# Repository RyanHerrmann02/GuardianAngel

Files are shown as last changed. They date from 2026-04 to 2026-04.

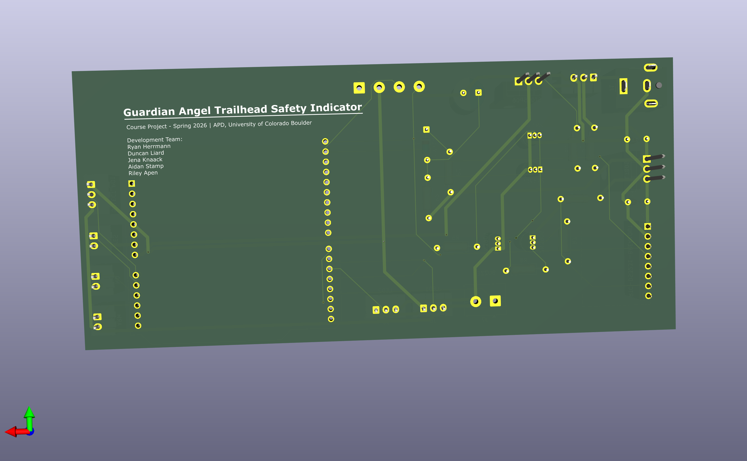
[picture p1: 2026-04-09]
ProtoBoard/Board_Rendering_Bottom.png

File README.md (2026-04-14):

# Guardian Angel
**Course Project — Spring 2026 | APD, University of Colorado Boulder**

## Overview
Guardian Angel is an Arduino-based trailhead safety indicator designed to assist 
Search and Rescue (SAR) personnel and other outdoor enthusiasts to communicate the status of
users when in the backcountry. This project was developed as part of the
Advanced Product Design (APD) course Spring 2026 at the University of Colorado Boulder.

## Hardware Architecture

### Power Management
A core engineering challenge of this project was designing a reliable power sequencing
system that allows the Arduino to control its own power state while also being woken
remotely by an RTC alarm all from a single LiPo battery source with no dedicated
power management IC.

#### Passive Power Latch (RC Hold Circuit)
To allow the Arduino to hold itself powered on after the user presses the power switch,
a passive PMOS-based power latch was designed and verified through SPICE simulation.
On power switch press, an RC circuit (47kΩ / 100µF, τ ≈ 4.7s) pulls the PMOS gate low
long enough for the Arduino to boot and assert its own hold pin, latching the board on
indefinitely. To enable fast and reliable resets, an asymmetric discharge path was
implemented using a 1kΩ resistor in series with a flyback diode in parallel with the
charge resistor, reducing the discharge time constant to ~100ms. This ensures the latch
clears quickly and cleanly between power cycles without requiring any active components.

#### RTC Wake Circuit (Discrete Transistor Level Shifter)
The DS3231 RTC module operates on a 5V rail that remains powered after the Arduino board 
is fully shut off, minimizing system current draw during the wait period. This allows the 
RTC to continue tracking time and fire a wake alarm via its open-drain SQW pin when the 
countdown expires. The PMOS transistor, which is responsible for gating battery voltage 
into the Arduino, requires its gate to be pulled low at battery voltage (~7.4V) to power 
the board back on a different domain from the 5V RTC supply. A two-stage discrete 
transistor circuit was designed to bridge these domains without connecting them directly. 
When the SQW pin fires and pulls low, current flows
through a PNP transistor biased from the 5V rail, whose collector output drives the base
of an NPN transistor referenced to ground. The NPN collector then pulls the PMOS gate
low at battery voltage, turning the board back on. This keeps the 5V RTC supply domain
fully isolated from the battery voltage domain while reliably translating the alarm signal
into a board power-on event.

---

## Future Development
Long-range wireless communication via LoRa radio integration is currently under 
consideration for future iterations of the project. This would enable communication 
between trail indicators and users within certain ranges. Implementation is subject 
to project timeline and scope constraints.

Developing a single board to handle functions with DS3231 breakout and a microcontroller
like the ATtiny for logic and pin control. This will also net in better power consumption
and longer battery life.

## Repository Contents
The following files are included in this repository:

| File | Description |
|---|---|
| `BasicBoardTesting.ino` | "Sandbox" for testing board pulldown transistor testing for utilizing PMOS for board power. |
| `GACarCommand.ino` | Primary device firmware handling LCD display, RTC alarm scheduling, and emergency lighting. |
| `HelloWorld.ino` | Basic LCD I2C display verification test. |
| `ProtoBoard` | Schematics and Gerber files for prototyped board using Arduino shield for component integration. Included is zip of Gerber drill files. |
| `RFReceiveCommand.ino` | Test file for receiving LoRa radio commands, displaying results on an LCD and controlling corresponding LEDs. |
| `RFSendCommand.ino` | Test file for transmitting LoRa radio commands, using a potentiometer to select color-coded signal states. |
| `RTCPullDown.ino` | Final testing with RTC breakout to verify SQW pin pulls down to turn on PMOS. |
| `SleepBreakouTest.ino` | Initial test code for RTC breakout to track time. |
| `SleepCommandDemo.ino` | Initial test code for UI interfacing with buttons and potentiometer to set time. |
| `TurnOnDemo.ino` | Basic verification for turn on and check for Alarm state. |

## Development Team
- Ryan Herrmann
- Duncan Liard
- Jena Knaack
- Aidan Stamp
- Riley Apen

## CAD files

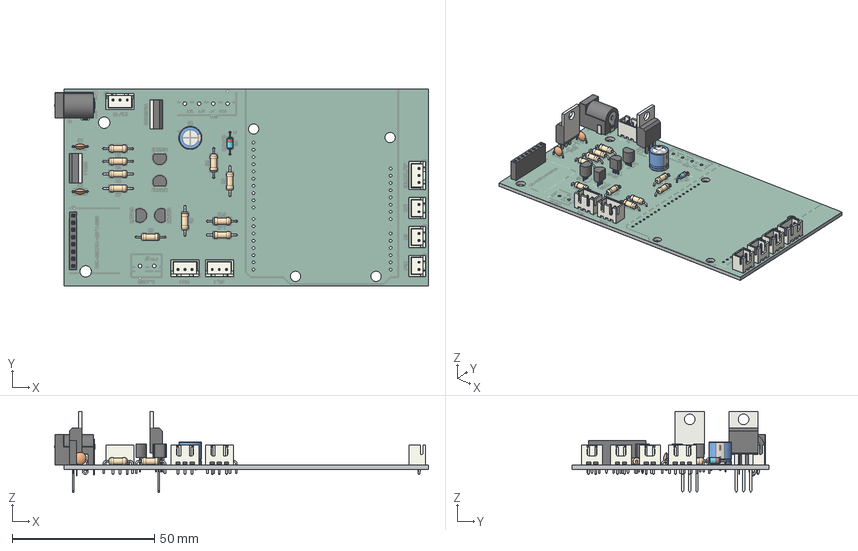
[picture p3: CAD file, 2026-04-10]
ProtoBoard/FullGACommand.step
131.6 x 69.2 x 28.5 mm
R_Axial_DIN0207_L6.3mm_D2.5mm_P10.16mm_Horizontal x 10
TO-220-3_Vertical x 2
BarrelJack_Horizontal
C_Disc_D4.3mm_W1.9mm_P5.00mm x 2
TO-92_Inline x 4
CP_Radial_D8.0mm_P3.80mm
PinSocket_1x08_P2.54mm_Vertical
JST_XH_B2B-XH-A_1x02_P2.50mm_Vertical x 3
JST_XH_B3B-XH-A_1x03_P2.50mm_Vertical x 4
D_DO-35_SOD27_P7.62mm_Horizontal
FullGACommand_silkscreen x 2
FullGACommand_soldermask x 2
FullGACommand_PCB

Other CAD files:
ProtoBoard/FullGACommand.stl

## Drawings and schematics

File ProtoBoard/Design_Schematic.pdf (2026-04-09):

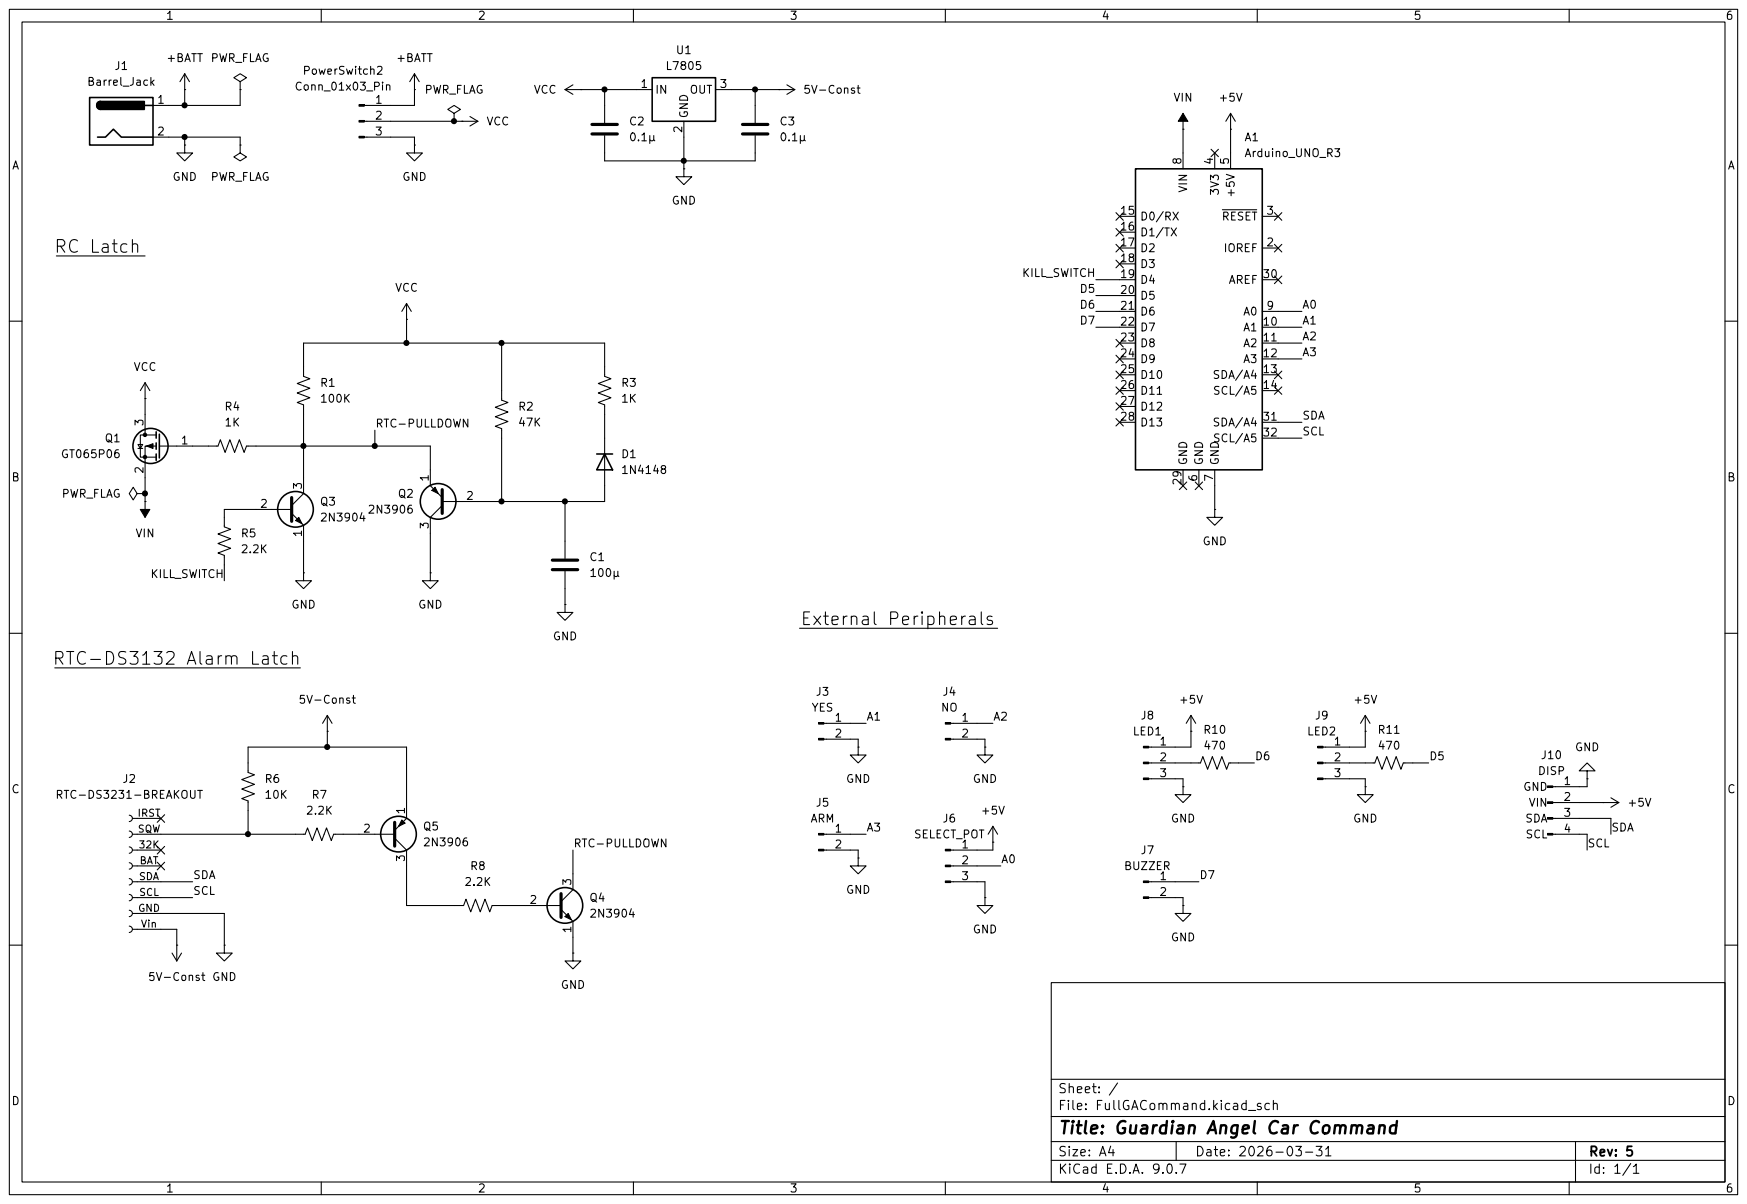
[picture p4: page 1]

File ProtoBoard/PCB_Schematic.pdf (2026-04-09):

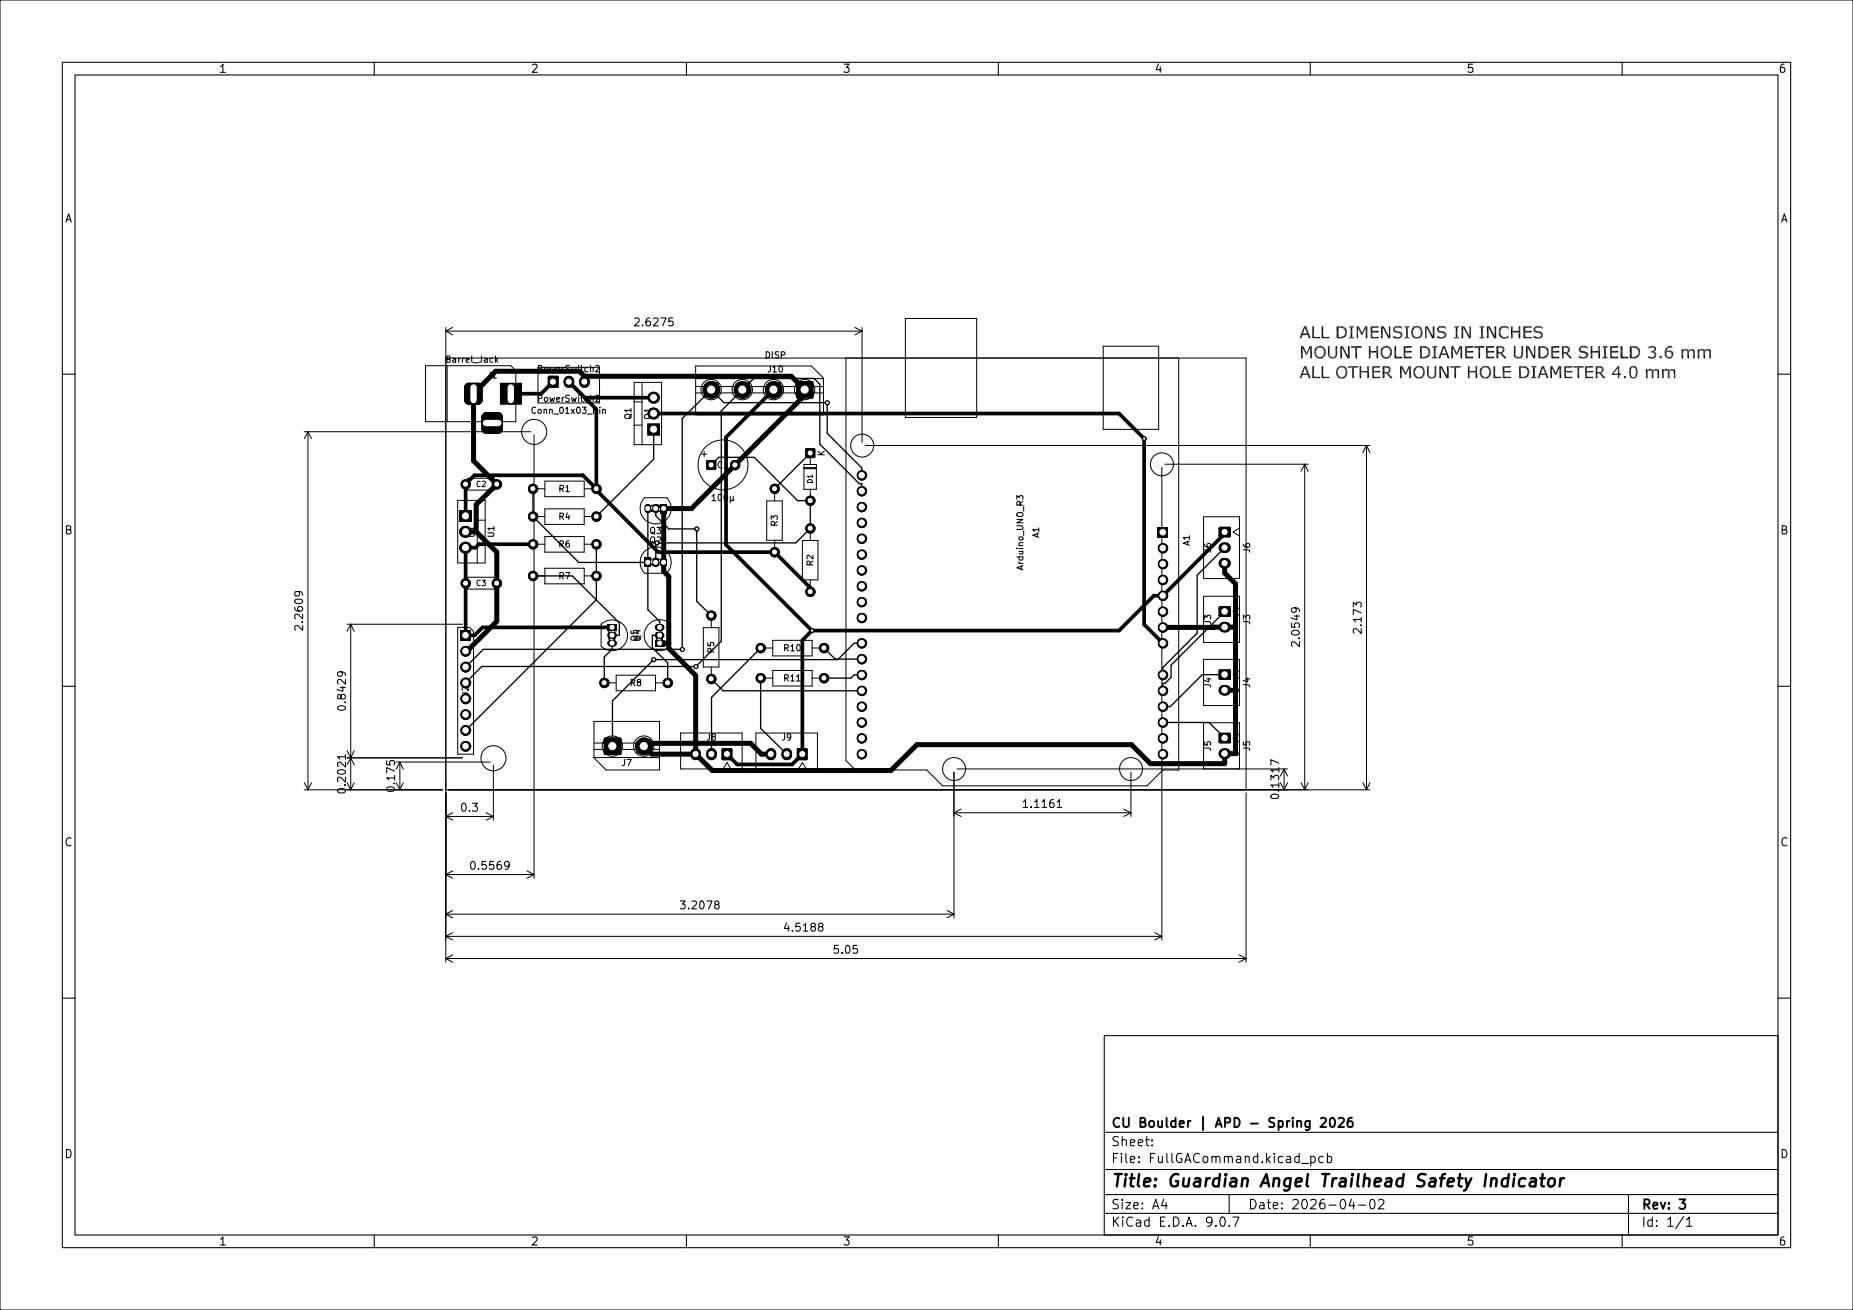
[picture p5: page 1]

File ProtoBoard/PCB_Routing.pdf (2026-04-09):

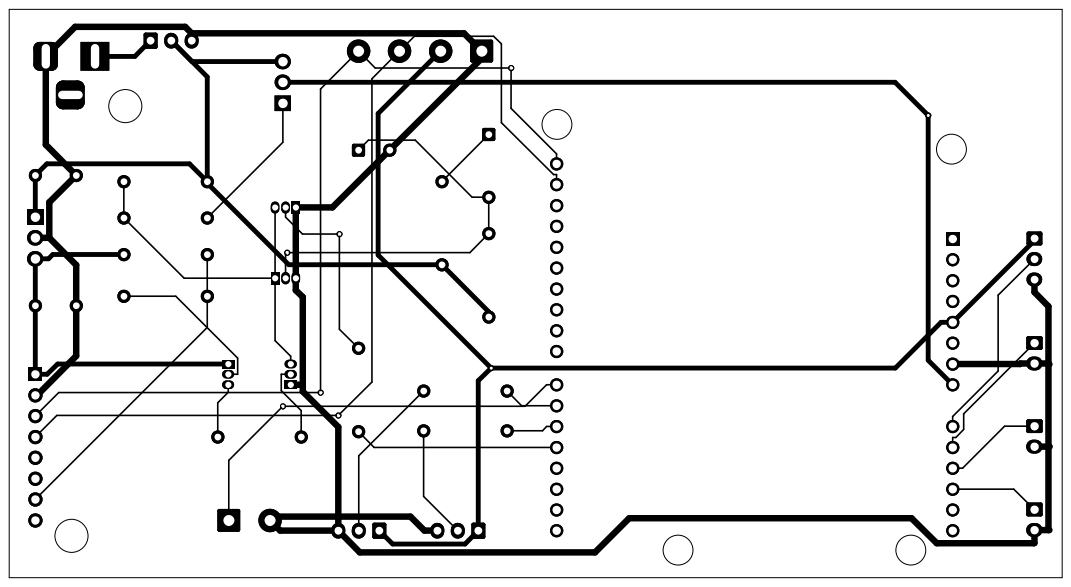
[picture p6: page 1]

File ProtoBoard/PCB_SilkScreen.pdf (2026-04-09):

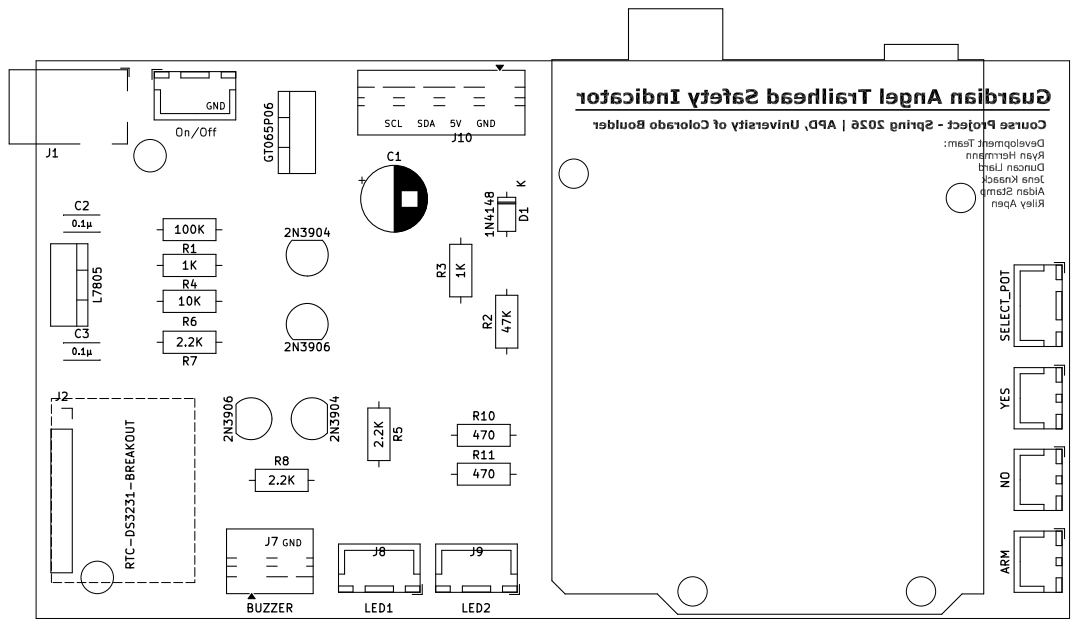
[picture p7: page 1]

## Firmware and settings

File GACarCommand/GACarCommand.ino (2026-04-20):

/*  Full code for the Guardian Angel Car Command:
    This code will handle the following functions, after turning on the device the 
    arduino will hold itself to high. It will also check to see if it was the RTC that 
    turned it back on or if it was done on startup. This will run the emergency command
    as well as setting sleep through UI. We will be implementing 4 input controls. It
    includes 3 buttons for prompts and timer setting. We implement I2C for less pinouts
    on the LCD display as well as Neopixel LEDs, and RTC for timer handling.*/

// Importing Necessary Libraries
#include <LiquidCrystal_I2C.h>
#include <Wire.h>
#include <RTClib.h>
#include <Adafruit_NeoPixel.h>

//Define Lights
#define BEEPER 7
#define EMERGENCY_LIGHT_1 6
#define EMERGENCY_LIGHT_2 5
#define NUMPIXELS 16

// Define the Scroll Wheel
#define SCROLL_PIN A0

// Define Buttons
#define BTN_YES A1
#define BTN_NO A2
#define BTN_KILL A1

// Define KillPin
#define KILL_SWITCH 4

// Declare and start Backpack
LiquidCrystal_I2C lcd(0x27, 16, 2);

// Declare Sleep Breakout
RTC_DS3231 rtc;

// Declare Pixel ring
Adafruit_NeoPixel pixels1(NUMPIXELS, EMERGENCY_LIGHT_1, NEO_GRB + NEO_KHZ800);
Adafruit_NeoPixel pixels2(NUMPIXELS, EMERGENCY_LIGHT_2, NEO_GRB + NEO_KHZ800);

// Declare sleep time variables
int days, hours, minutes;

// Declare DateTime formats to use
DateTime startTime;
DateTime targetTime;

// For button pressing logic, create enum datatype
enum ButtonPress {NONE, YES, NO};

// Button Press YES NO logic.
ButtonPress readButtons()
{
  if (digitalRead(BTN_YES) == LOW)
  {
      delay(50); // debounce: Checks to make sure not noise
      if (digitalRead(BTN_YES) == LOW)
          return YES;
  }
  if (digitalRead(BTN_NO) == LOW)
  {
      delay(50); // debounce 
      if (digitalRead(BTN_NO) == LOW)
          return NO;
  }
  return NONE;
}

/*-----------------------------------------------------------
  The following code handles the emergency scenario it will
  function be simultaneously beeping and flashing red lights
  on an interval. Emergency does that while the
  ledLightSetup handles starting the rings. Important to wait
  to set them up until later so that the current pull is low
-----------------------------------------------------------*/
// Emergency Alert Code
void emergency()
{
  uint32_t red = pixels1.Color(255, 0, 0);  // Red warning color

  // First beep + flash
  pixels1.fill(red);      // turn all LEDs on
  pixels2.fill(red);
  pixels1.show();
  pixels2.show();
  tone(BEEPER, 1000);     // 1 kHz beep
  delay(200);             // beep & flash duration

  pixels1.clear();        // turn LEDs off
  pixels2.clear(); 
  pixels1.show();       
  pixels2.show();
  noTone(BEEPER);         // stop beep
  delay(150);             // short gap between beeps

  // Second beep + flash
  pixels1.fill(red);
  pixels2.fill(red);
  pixels1.show();
  pixels2.show();
  tone(BEEPER, 1000);
  delay(200);

  pixels1.clear();
  pixels2.clear();
  pixels1.show();       
  pixels2.show();
  noTone(BEEPER);

  delay(800);         // long pause before repeating
}

// Setting up LED Ring Lights as RED
void ledLightSetup()
{
  pixels1.begin();
  pixels1.setBrightness(60);    //0 - 255

  pixels2.begin();
  pixels2.setBrightness(60);    //0 - 255
}

/*-----------------------------------------------------------
  The following code here is in charge of creating
  a menu where the user can select the time that they
  want the alarm to go off for, this is all UI so they can
  go back and forth between menus as well as wait to 
  start the timer until they are ready. Once ready, the
  timer will be primed for the user to press the button kill
  switch
-----------------------------------------------------------*/
void timeSelection()
{
  // Force I2C to update at slower refresh rate
  unsigned long lastLCDUpdate = 0;
  const int LCD_UPDATE_INTERVAL = 200; // only update every 200ms

  // Create the menu at the top of the Display and move to the next
  lcd.clear();
  lcd.setCursor(0,0);
  lcd.print("Time Selection");
  lcd.setCursor(0,1);

  // Menu Switching
  bool inDayMenu = 1;
  bool inHourMenu = 0;
  int lastDays = -1;
  int lastHours = -1;

  // Create the days and hours to be set on RTC
  int daySelect = 0;
  int hourSelect = 0;

  while (inDayMenu)
  {
    // Selection of Days
    daySelect = map(analogRead(SCROLL_PIN), 0, 1023, 0, 20);

    if (daySelect != lastDays && millis() - lastLCDUpdate > LCD_UPDATE_INTERVAL)
    {
      lcd.setCursor(0,1);
      lcd.print(daySelect);
      lcd.print(" Days           ");
      lastDays = daySelect;
      lastLCDUpdate = millis();
    }
    
    ButtonPress btnDay = readButtons();
    if (btnDay == YES)
    {
      delay(100);
      inHourMenu = 1;
      
      // Selection of Hours
      while(inHourMenu)
      {
        hourSelect = map(analogRead(SCROLL_PIN), 0, 1023, 0, 23);

        if (hourSelect != lastHours && millis() - lastLCDUpdate > LCD_UPDATE_INTERVAL)
        {
          lcd.setCursor(0,1);
          lcd.print(hourSelect);
          lcd.print(" Hours          ");
          lastHours = hourSelect;
          lastLCDUpdate = millis();
        }

        ButtonPress btnHour = readButtons();

        if (btnHour == YES)
        {
          lcd.clear();
          lcd.setCursor(0,0);
          lcd.print("Time Selected");
          lcd.setCursor(0,1);
          lcd.print(daySelect);
          lcd.print("d ");
          lcd.print(hourSelect);
          lcd.print("h");
          delay(3000);
          inHourMenu = 0;
          inDayMenu = 0;
          break;
        }

        else if (btnHour == NO)
        {
          delay(100);
          inHourMenu = 0;
          inDayMenu = 1;
          lcd.clear();
          lcd.setCursor(0,0);
          lcd.print("Time Selection");
          lcd.setCursor(0,1);
        }
      }
    }
  }

  days = daySelect;
  hours = hourSelect;
  minutes = 0;
}

// Ask to start timer
bool timerStart()
{
  lcd.clear();
  lcd.setCursor(0,0);
  lcd.print("Time selected?");
  lcd.setCursor(0,1);
  lcd.print("Yes/No");

  while(1)
  {
    ButtonPress btn = readButtons();
    if (btn == YES)
    {
      lcd.clear();
      return true;
    }
    else if (btn == NO)
    {
      lcd.clear();
      return false;
    }
  }
}

// Start by Initializing the LCD Screen Startup
void lcdInitializationSetup()
{
  for (int i = 0; i <= 3; i++)
  {
    lcd.setCursor(0,0);
    lcd.print("Starting");
    for (int j = 0; j < i; j++) lcd.print(".");
    lcd.print("        "); // clear trailing characters
    delay(500);
  }
  lcd.clear();
}
// Setup and start the timer for alarm
void RTCSetup()
{
  // Start the RTC Breakout
  rtc.adjust(DateTime(2000, 1, 1, 0, 0, 0)); // Setting arbitrary start time to start at
  delay(50);  // Give the RTC a sec to get all setup to avoid calling code and then messing up the setup

  // Create start and end times for the breakout
  startTime = rtc.now();
  targetTime = startTime + TimeSpan(days, hours, 0, 0); //To be set by adjusting on display

  // Clear alarms
  rtc.clearAlarm(1);
  
  // Disable second alarm
  rtc.disableAlarm(2);
}

// Sets the alarm and turns off power to main arduino board.
void armAlarm() 
{
  lcd.clear();
  lcd.print("To set alarm,");
  lcd.setCursor(0,1);
  lcd.print("press YES Button");
  delay(500);

  while(1)
  {
    if (digitalRead(BTN_KILL) == LOW)
    {
      break;
    }
  }

  // Setup timer to get start and stop time
  RTCSetup();

  // Start Alarm
  rtc.setAlarm1(targetTime, DS3231_A1_Date);
  delay(100);

  // Kill power to board
  digitalWrite(KILL_SWITCH, LOW);
}

void setup() 
{
  // For every start, check alarm and make kill pin high.
  pinMode(KILL_SWITCH, OUTPUT);
  digitalWrite(KILL_SWITCH, HIGH);

  delay(1000);
  Wire.begin();
  Wire.setWireTimeout(3000, true);  //Keeping wire timeout for testing if lights off then same issues
  rtc.begin();

  // Have LCD Initialize so that know is on
  delay(1000);
  lcd.init();
  lcd.init();
  lcd.backlight();

  // Scroll wheel and button Setup
  pinMode(BTN_YES, INPUT_PULLUP);
  pinMode(BTN_NO, INPUT_PULLUP);
  pinMode(BTN_KILL, INPUT_PULLUP);

  // If alarm fired, run emergency, if not run setup protocol
  if(rtc.alarmFired(1))
  {
    // Clear Alarm after wake
    rtc.clearAlarm(1);

    // Setup Alarm Lights
    ledLightSetup();

    // Print Missing Person alert on LCD
    lcd.print("MISSING PERSON:");
    lcd.setCursor(0,1);
    lcd.print("CALL S.A.R");
    
    while(1)
    {
      emergency();
    }
  }
  else
  {
    lcdInitializationSetup(); // To be removed later this is validation testing so user can see it is on

    // Handle the menu logic for time selection
    bool timerConfirmed = false;
    while(!timerConfirmed)
    {
      timeSelection();
      timerConfirmed = timerStart();
    }
    
    // Start the hibernation and alarm for wake
    armAlarm();
  }
}

void loop() {
  // put your main code here, to run repeatedly:
}

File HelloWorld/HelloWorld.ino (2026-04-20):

#include <Wire.h>
#include <LiquidCrystal_I2C.h>

LiquidCrystal_I2C lcd(0x27, 16, 2);
void setup() {
  
  Serial.begin(9600);
  delay(1000);
  Wire.begin();
  
  Serial.println("Scanning...");
  for (byte addr = 1; addr < 127; addr++) {
    Serial.println(addr);
    Wire.beginTransmission(addr);
    if (Wire.endTransmission() == 0) {
      Serial.print("Found device at: 0x");
      Serial.println(addr, HEX);
    }
  }
  Serial.println("Done.");
  // put your setup code here, to run once:
  lcd.begin(16,2);
  lcd.setBacklight(1);
  lcd.print("Hello World!");
}

void loop() {
  // put your main code here, to run repeatedly:
  lcd.setCursor(0, 1);
  lcd.print(millis() / 1000);
  //Serial.println(millis()/1000);
}

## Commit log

2026-03-11 Adjusted button edge case double press
2026-03-12 feat: LED Alert System
    Added LED alert on wake, includes turning backlight off when asleep
2026-03-24 Add Sleep Demo; Update Hello World
    - Add new sleep demo to use breakout
    - Update: Hello World now uses I2C Backback from Adafruit
2026-03-25 Add: TurnOnDemo Update: GACarCommand SleeepCommand
    Update: Car Command now fully updated with time selection 2 alarm blinks, deep sleep with interrupt and beeper
    Update: SleepCommand changed for moving functions to Car command
    Add: New code for PMOS attempt
2026-03-26 Update: Car Command Issue: Car Command
    Update: Car command updated to find date in line 215 not second or minute. Adjusted timings for smoother operatiion
    Issue: Time selection flickering possibly due to Potentiometer soldering or wiring, however the voltage will bounce creating issue with display time check. Thus flickering
    [GACarCommand.ino]
2026-03-31 Add Board Testing
    Added board testing to be changed for various testing with PMOS turn off and turn on systems
2026-04-02 Update Car Command
    Car command now handles inputs and RTC breakout without any Sleep. RTC will just turn board back on
2026-04-09 Update GACarCommand
    Updated car command for slower LCD refresh rate for issues with Arduino timeout
    [GACarCommand.ino]
2026-04-10 Add GACommand STL File
    [FullGACommand.stl]
2026-04-10 Add GACommand STEP file
    [FullGACommand.step]
2026-04-20 Update GACarCommand HelloWorld
    Changed I2C backpack away from Adafruit
